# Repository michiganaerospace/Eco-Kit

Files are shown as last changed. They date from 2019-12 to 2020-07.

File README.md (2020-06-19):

# Eco-Kit
A Enviornmental Monitoring Kit

This is an Enviromental Monitoring Kit which M.A.C. has created in order to access live weather data easily.

To install the Eco Kit app you will want to download the github repository.

Windows: navigate to weather ui windows on an Anaconda Prompt. Type "pip install -r requirments.txt" . 
It should install the required librarys to the anaconda program and if all is successful its ready to run the windows application.

Mac: navigate to anaconda prompt and follow the directions in the "install text.txt" file. 

To run the application we use the spyder program included in the anaconda package.
You will want to go up to the top of spyder and open the file of the windows or macintosh version of the ECO Kit program.
It should be ready to run after that.

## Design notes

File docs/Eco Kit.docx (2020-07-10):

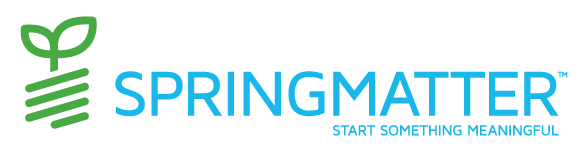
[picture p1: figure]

ECO KIT

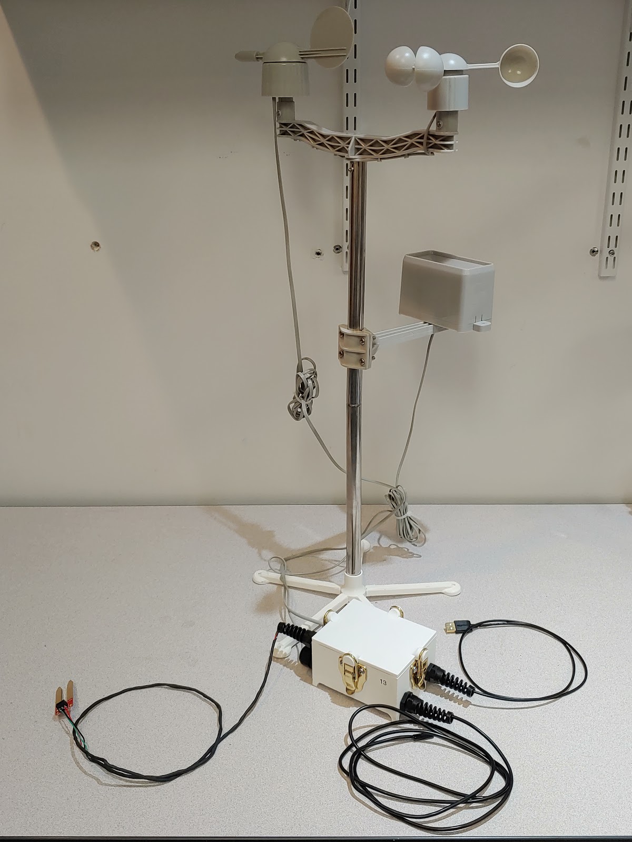
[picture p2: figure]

Table of content

WIFI setup – 3

Eco Kit setup – 3

Photon color codes - 3

Downloading the weather app- 4

Running App - 5

Using App – 6

Getting the Data from the Photon - 7

Setting Up Google Sheets - 8

Adding new weather station to weather app - 16

Connecting Wi-Fi to photon:

1. Power up photon
2. Navigate to https://setup.particle.io
3. Select Photon
4. Press continue with local file and download the setup file
5. Click the download and a new window should open up
6. Hold down SETUP on your Photon for 3 seconds until the LED begins blinking dark blue

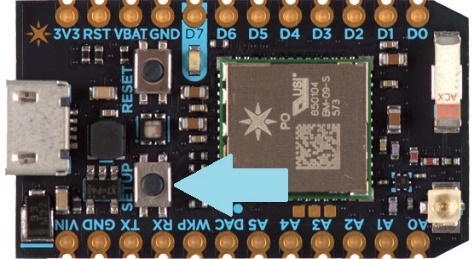
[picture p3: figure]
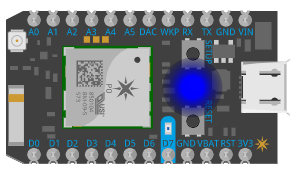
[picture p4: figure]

7. From your Wi-Fi network list, connect to the one named 'Photon-...'
8. If it displays “Error: HTTP timed out” reload the page
9. If your photon is breathing cyan you successfully connected

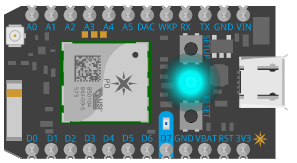
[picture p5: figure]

10. Select complete setup without naming your device
11. You can exit the page now

Eco Kit setup

1. Find a flat location to setup the Eco Kit
2. Place the soil moisture sensor and soil temperature sensor into dirt that you want to monitor
3. Plug the usb cable into a computer or USB wall charger to power the system up
4. The weather station should start reporting data
5. If data isn't reporting check the inside of the box and the photon board status will be displayed by the color it is emitting

Photon color codes

Breathing cyan - Board is connected to wifi

Blinking cyan - Actively connecting to wifi

Blinking green - Looking for wifi

Blinking dark blue - waiting for you to setup wifi

Breathing dark blue - wifi on but cannot connect to network

Breathing green - not connected to cloud

Downloading the weather app

1. Download a python ide for this app we will use anaconda.
2. Go to https://www.anaconda.com/distribution/#download-section and download the latest anaconda version for your operating system
3. Once anaconda is downloaded type in “Anaconda Navigator” to your search bar and left click “Anaconda Navigator”
4. Click launch on the Spyder app

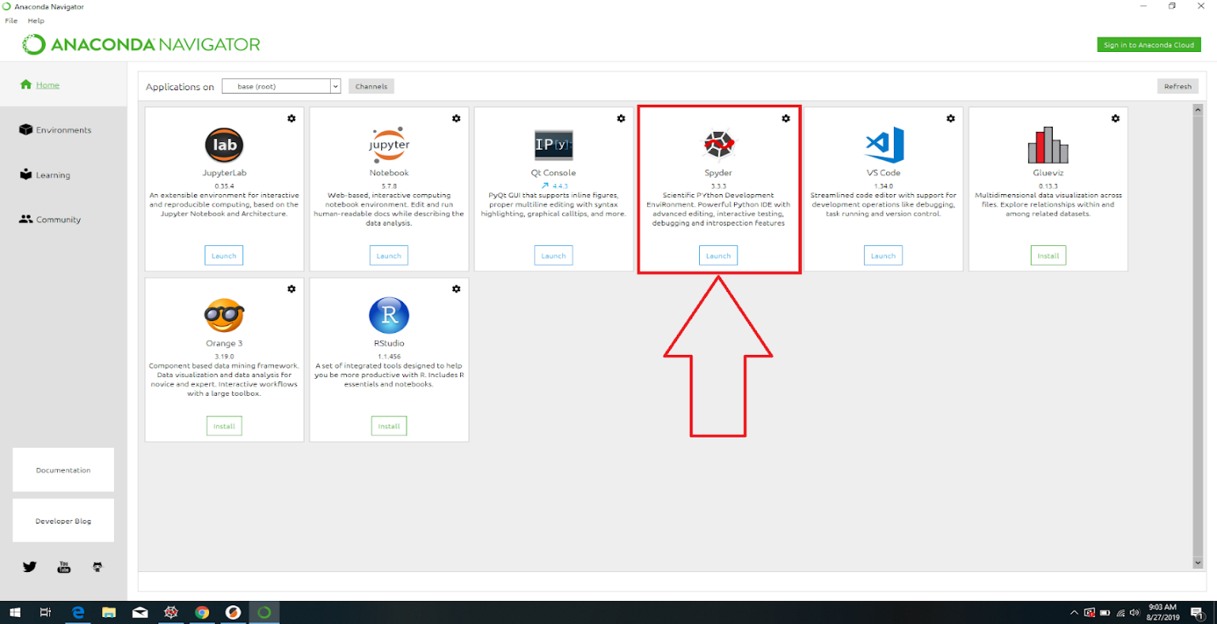
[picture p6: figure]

5. Type “pip install gspread” and “pip install oauth2client” into the console located in the right side of the screen

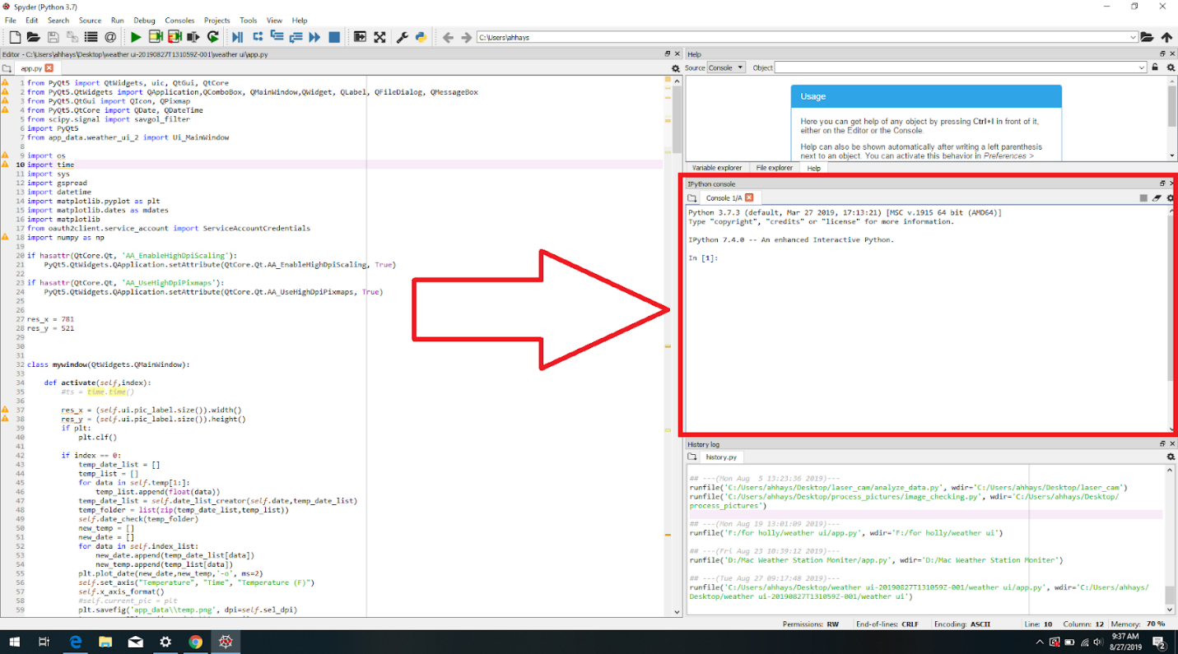
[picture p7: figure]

Running app

1. Launch Anaconda Navigator
2. Select launch on Spyder

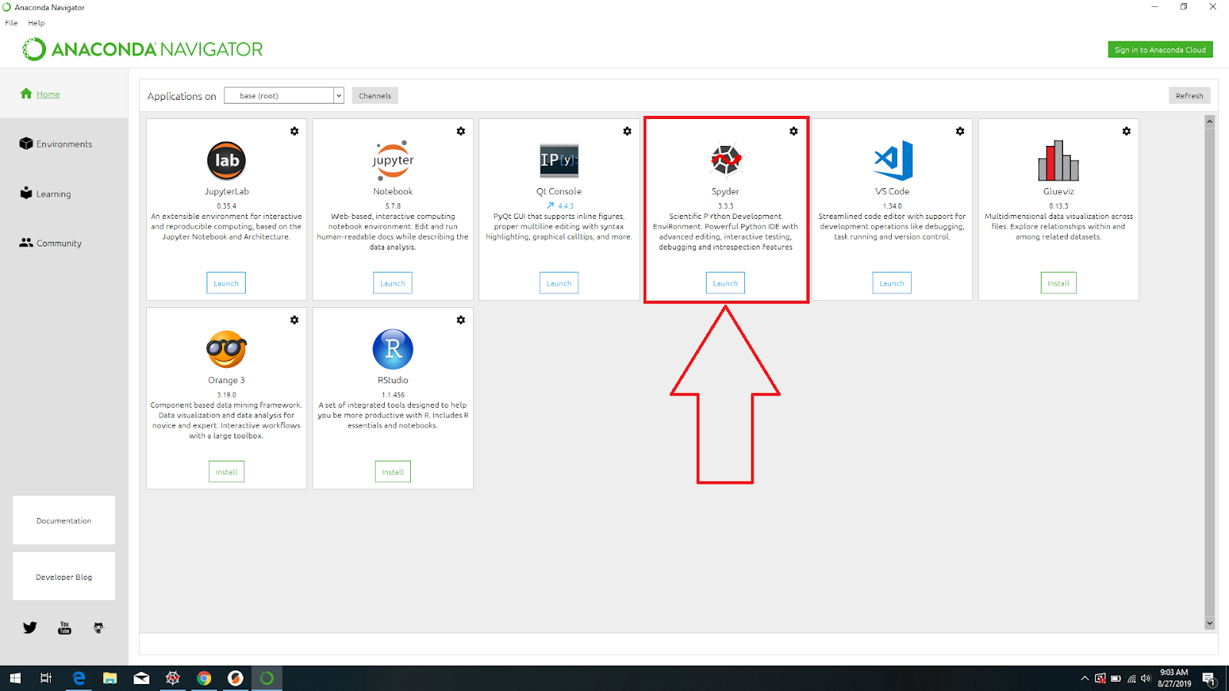
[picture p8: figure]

3. Select file from top right of spyder window and select “open”
4. Navigate to app.py in the weather ui folder and open it
5. Run app by selecting green arrow in the top of the spider window

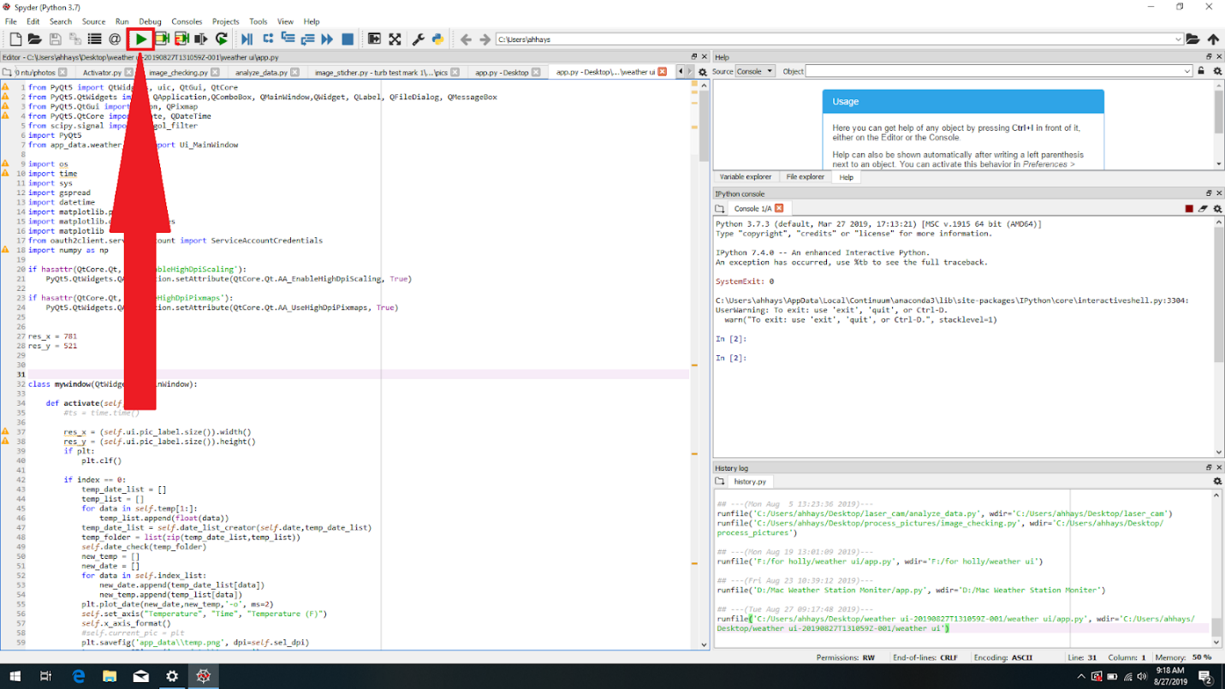
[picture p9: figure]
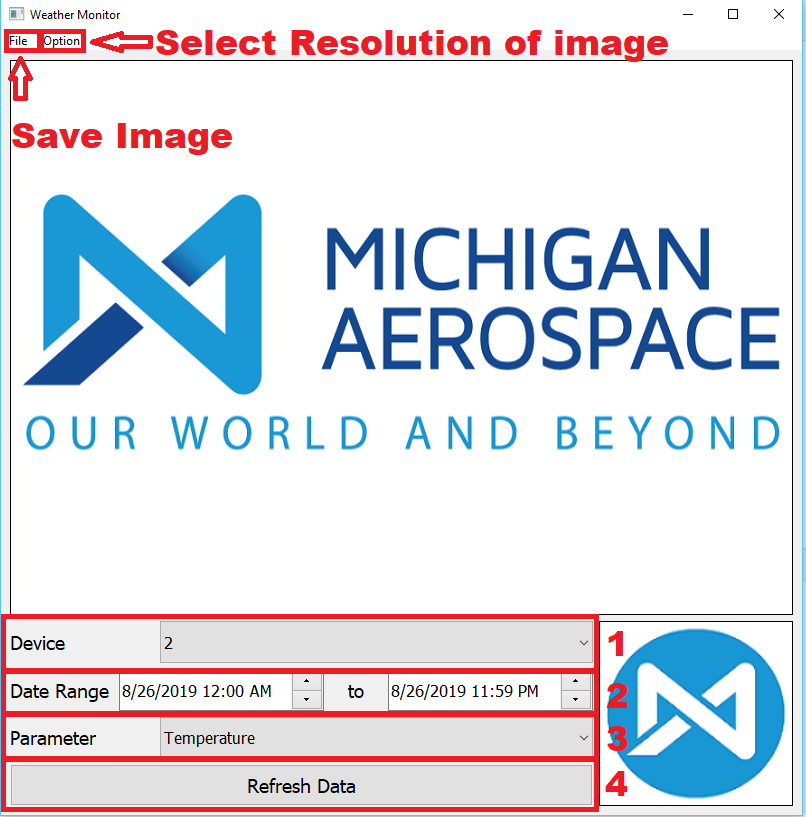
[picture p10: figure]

Once you have the Weather Monitor app running to get data you will need to:

1. Select a Device
2. Choose the data range of data that you want to see
3. Select which weather phenomenon you want to see
4. Then hit refresh data to obtain a graph of the data
5. This app downloads the data from google sheets and uses it to create these graphs. When you refresh data, it will take the newest points in the data range from google sheets if it doesn’t already have them.
6. To save the image, select file on the top left of the window and then save image and select the directory you want to save the image to.
7. To improve the resolution of this image, select options at the top left of the window and change the image resolution to a higher dpi

Getting the Data from the Photon

1. Go to particle.io
2. Login with openworlds@springmatter.org and the password Storm1777
3. Now, go to build.particle.io
4. First you will need to flash the Operation_Phoenix code to your device. To do so, you should click the two arrows on the side of the screen then click on Operation_Phoenix.

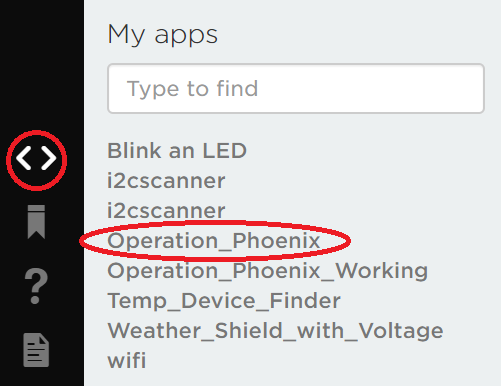
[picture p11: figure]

5. Once you have selected the correct device in the bottom right corner, click on the lightning bolt in the top left corner.
6. Once you have flashed the code to your device, the photon will begin to send data to Particle.io because of the Particle.publish line in the code.

Line 312 is the line you can change to modify the time between readings. If you change it you will need to reflash the code.

7. You can see data being published in the Particle.io Console

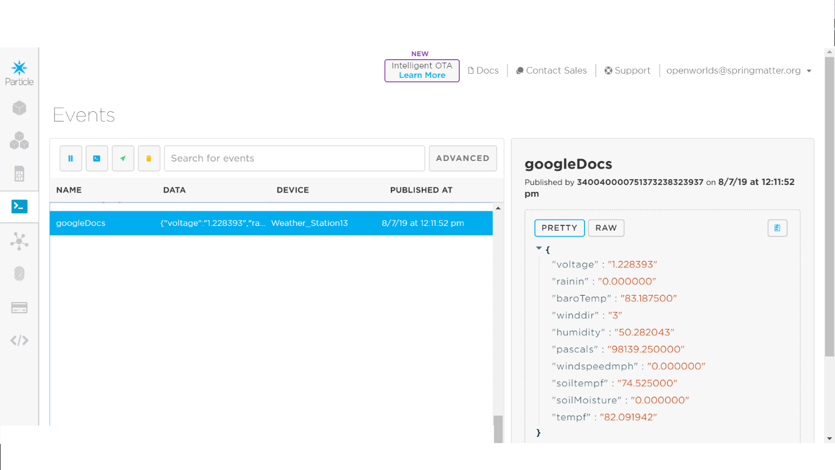
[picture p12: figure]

Setting Up Google Sheets

1. Once there is data streaming into Particle.io you can set up a Google sheet for a webhook to send this data to. You must use google chrome to get this to work
2. Login to the email: michiganaerospace1@gmail.com password: michaero
3. Create a new Google Sheet in Google Drive and Name it (Weather Station #)
4. Once you open your google sheet, you need to name the columns as shown below
5. Next you need to open the script editor in Google Sheets. To do this click on the Tools tab at the top, the click on Script editor

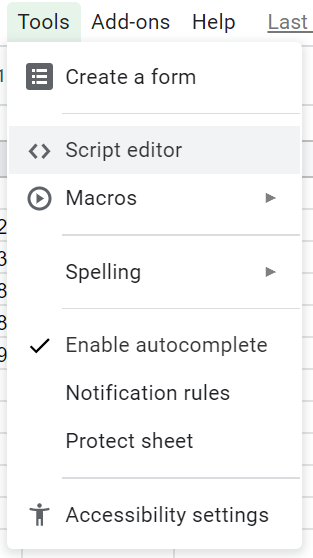
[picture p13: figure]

6. A Screen like this will pop up. Give the project a name (Weather Station # Project)

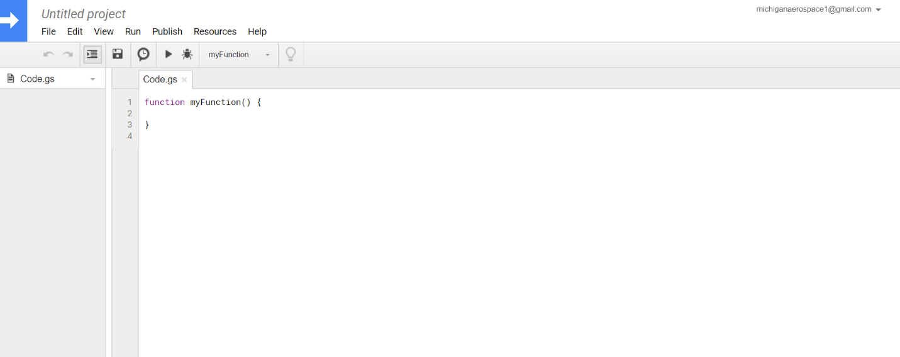
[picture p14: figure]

7. Delete what is currently under Code.gs and paste this code:

// original from: http://mashe.hawksey.info/2014/07/google-sheets-as-a-database-insert-with-apps-script-using-postget-methods-with-ajax-example/

function doGet(e){

return handleResponse(e);

}

// Usage

// 1. Enter sheet name where data is to be written below

var SHEET_NAME = "Sheet1";

// 2. Run > setup

//

// 3. Publish > Deploy as web app

// - enter Project Version name and click 'Save New Version'

// - set security level and enable service (most likely execute as 'me' and access 'anyone, even anonymously)

//

// 4. Copy the 'Current web app URL' and post this in your form/script action

//

// 5. Insert column names on your destination sheet matching the parameter names of the data you are passing in (exactly matching case)

var SCRIPT_PROP = PropertiesService.getScriptProperties(); // new property service

// If you don't want to expose either GET or POST methods you can comment out the appropriate function

function doPost(e){

return handleResponse(e);

}

function handleResponse(e) {

// shortly after my original solution Google announced the LockService[1]

// this prevents concurrent access overwritting data

// [1] http://googleappsdeveloper.blogspot.co.uk/2011/10/concurrency-and-google-apps-script.html

// we want a public lock, one that locks for all invocations

var lock = LockService.getPublicLock();

lock.waitLock(30000); // wait 30 seconds before conceding defeat.

try {

// next set where we write the data - you could write to multiple/alternate destinations

var doc = SpreadsheetApp.openById(SCRIPT_PROP.getProperty("key"));

var sheet = doc.getSheetByName(SHEET_NAME);

// we'll assume header is in row 1 but you can override with header_row in GET/POST data

var headRow = e.parameter.header_row || 1;

var headers = sheet.getRange(1, 1, 1, sheet.getLastColumn()).getValues()[0];

var nextRow = sheet.getLastRow()+1; // get next row

var row = [];

// loop through the header columns

for (i in headers){

if (headers[i] == "Timestamp"){ // special case if you include a 'Timestamp' column

row.push(new Date());

} else { // else use header name to get data

row.push(e.parameter[headers[i]]);

}

}

// more efficient to set values as [][] array than individually

sheet.getRange(nextRow, 1, 1, row.length).setValues([row]);

// return json success results

return ContentService

.createTextOutput(JSON.stringify({"result":"success", "row": nextRow}))

.setMimeType(ContentService.MimeType.JSON);

} catch(e){

// if error return this

return ContentService

.createTextOutput(JSON.stringify({"result":"error", "error": e}))

.setMimeType(ContentService.MimeType.JSON);

} finally { //release lock

lock.releaseLock();

}

}

function setup() {

var doc = SpreadsheetApp.getActiveSpreadsheet();

SCRIPT_PROP.setProperty("key", doc.getId());

}

8. Save this code then Run setup.

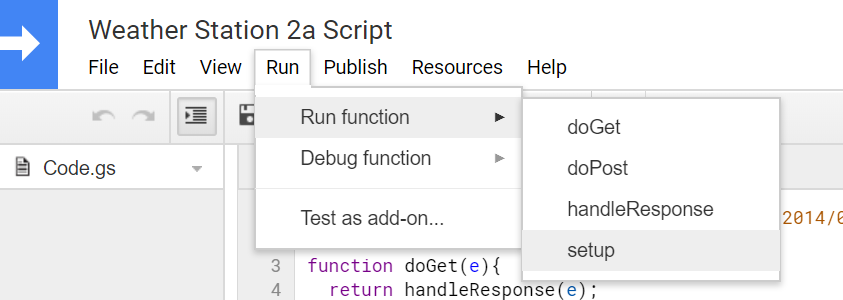
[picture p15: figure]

9. A screen will come up about permissions with the document. You will need to hit advanced settings then allow.
10. Next, click on the Publish tab and the Deploy as a Web App

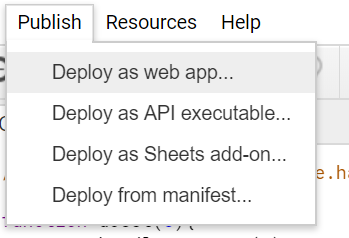
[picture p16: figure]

11. That will bring up this screen:

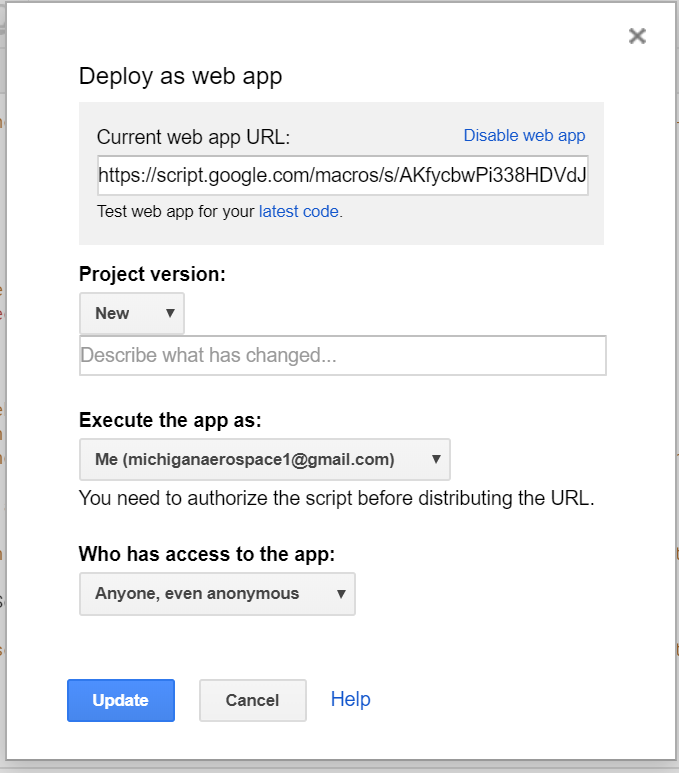
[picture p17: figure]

12. Set the Project version to new, the execute app as to Me and the access to anyone even anonymous. Click Deploy.
13. That will bring up this screen:

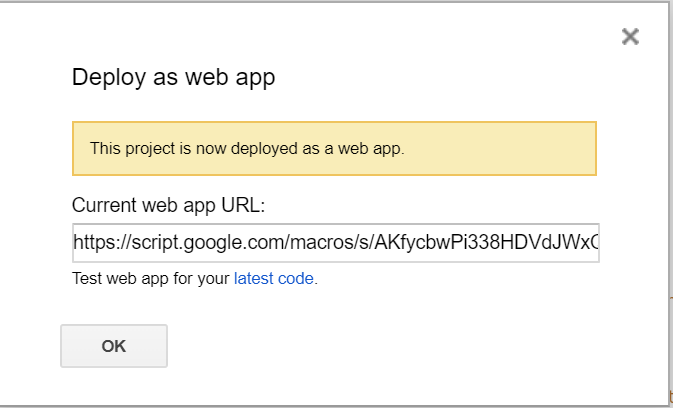
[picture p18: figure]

14. Copy the Current web app URL to be used in a Particle Webhook and click OK

Setting Up a Particle Webhook

1. Open the Particle.io console and click on integrations
2. Click on new integration

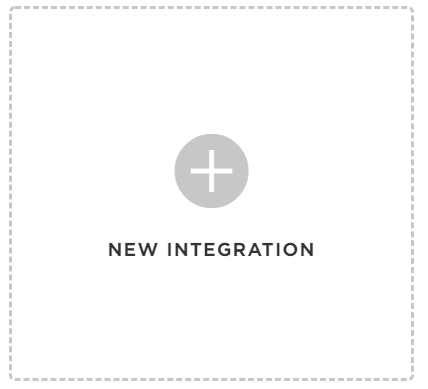
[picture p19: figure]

3. Click on Webhook
4. Enter the event name googleDocs. Paste the URL you copied from the google script. Select your device.

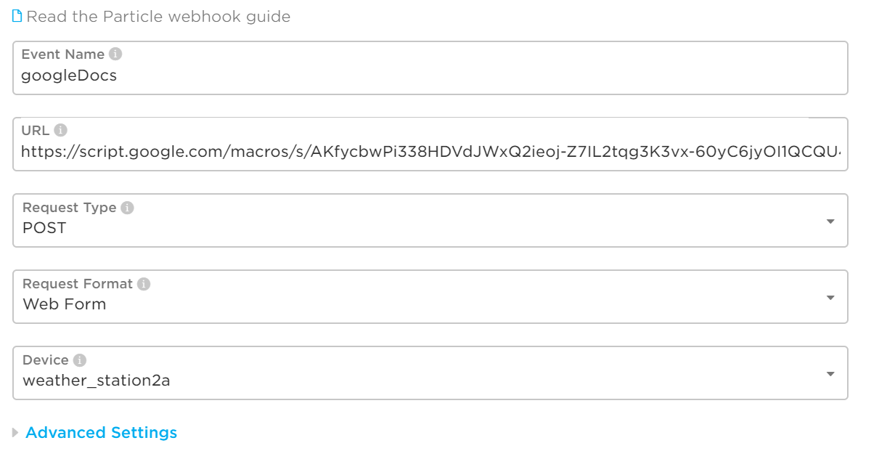
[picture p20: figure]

5. Click on Advanced Settings then custom for form fields. Enter each field as seen below

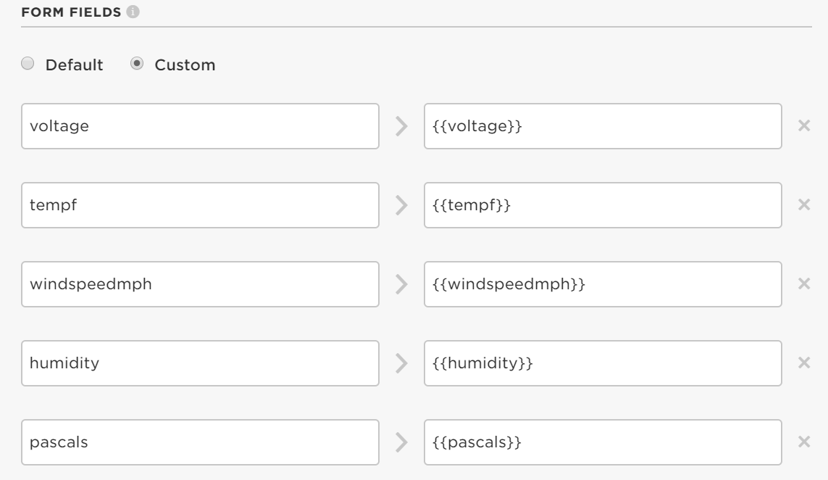
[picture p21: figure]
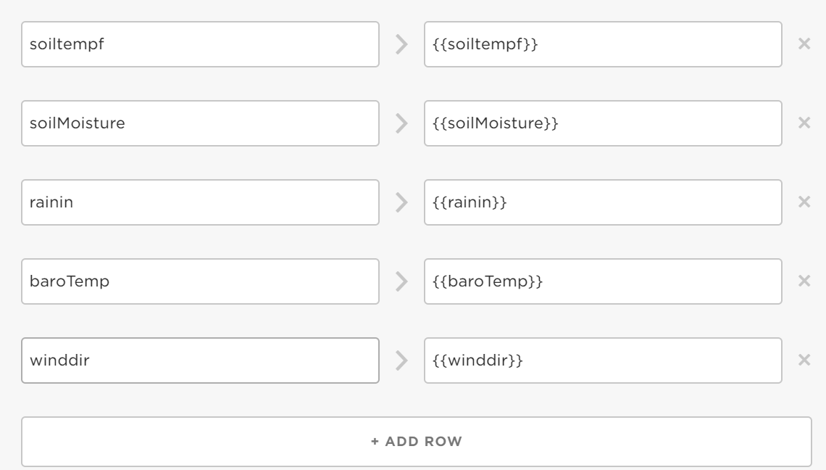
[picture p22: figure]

6. Under Http Headers enter as seen below

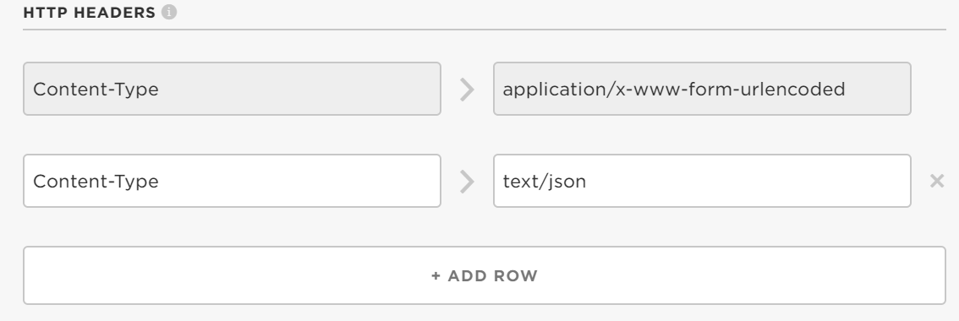
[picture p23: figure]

7. At the bottom of the page click create webhook. If you are editing your webhook, you will need to hit save.
8. You should now be able to go to the events tab on the Particle.io console and see hooks being sent to Google Sheets

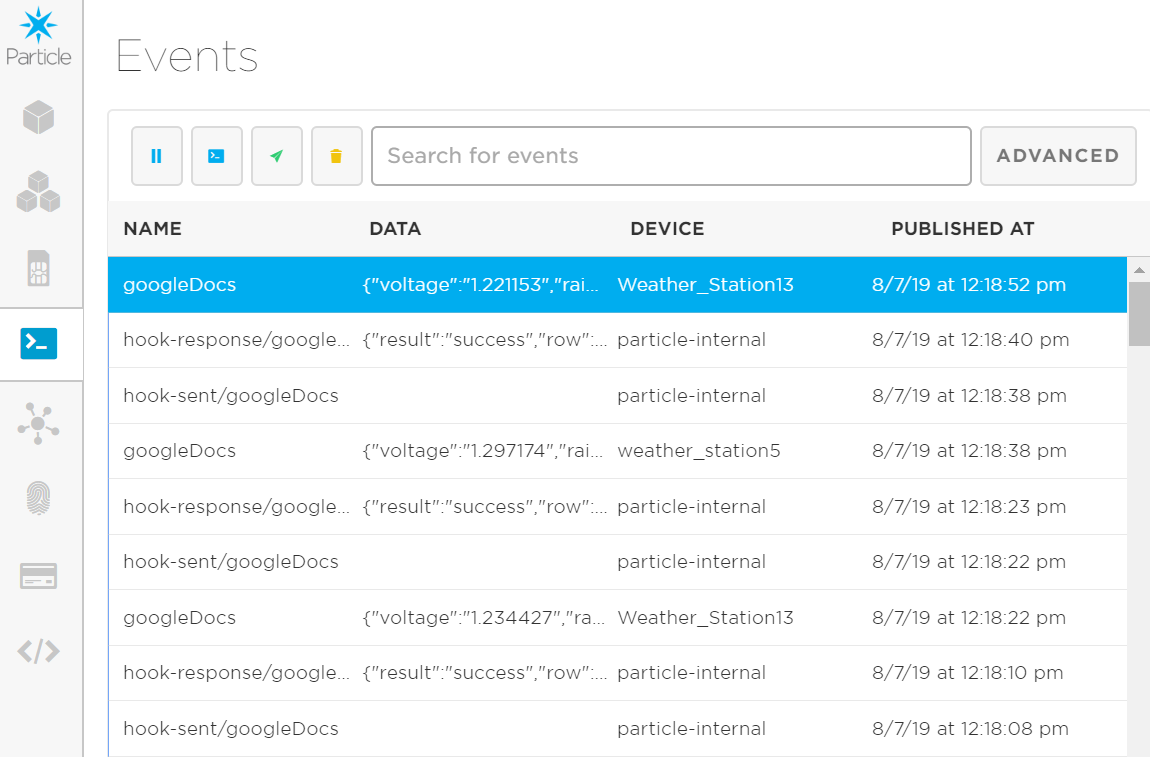
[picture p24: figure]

9. Data should now be streaming in your Google Sheet

Adding new weather station to weather app

1. Navigate to the client secret file located in the app_data or main folder
2. Right click and select edit
3. Select and copy the client_email which is “weather@weather-247217.iam.gserviceaccount.com”
4. Return to the google sheet and share this with our client_email so it can access the sheet.
5. Run the weather app if not familiar check the section on running the app
6. In the top left section of weather app select option and then Add Device
7. A pop-up window should ask you the number of your weather station
8. Enter the weather station number from your google sheets example (Weather Station 5) just enter “5”

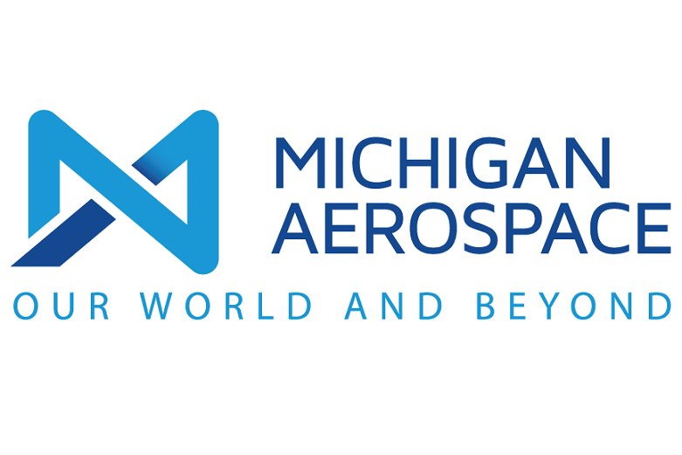
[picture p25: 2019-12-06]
weather ui windows/app_data/MAC-Decal-MASTER.png

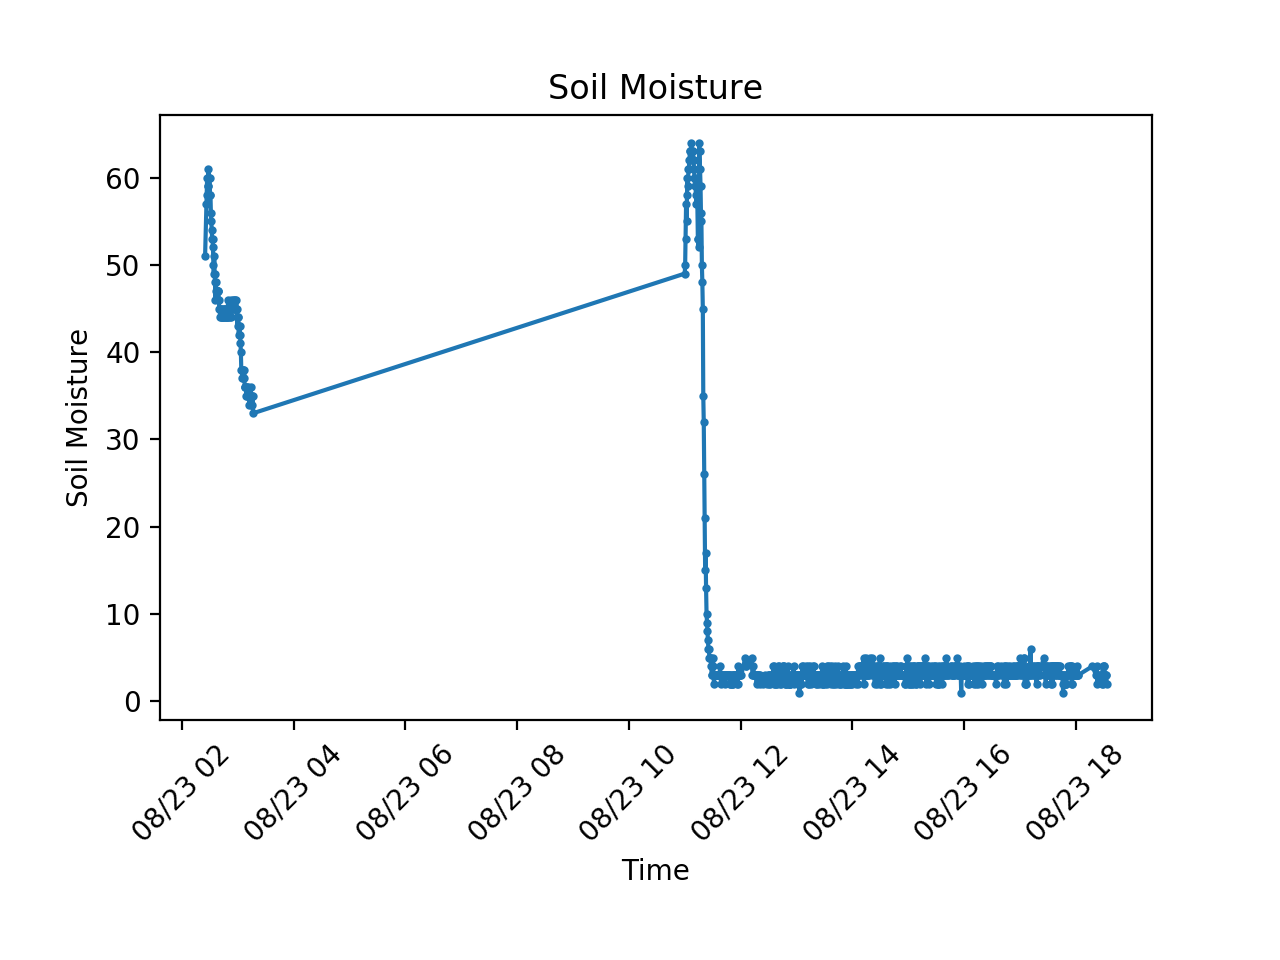
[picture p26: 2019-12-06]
weather ui mac/sm.png

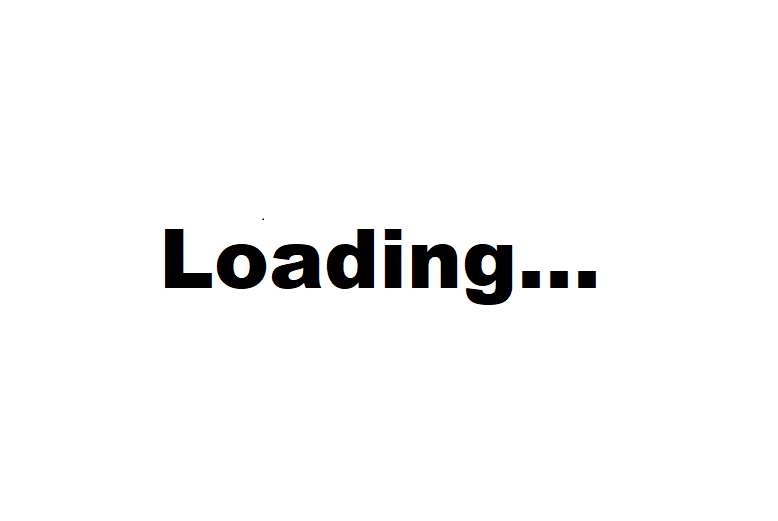
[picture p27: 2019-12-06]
weather ui mac/loading.png

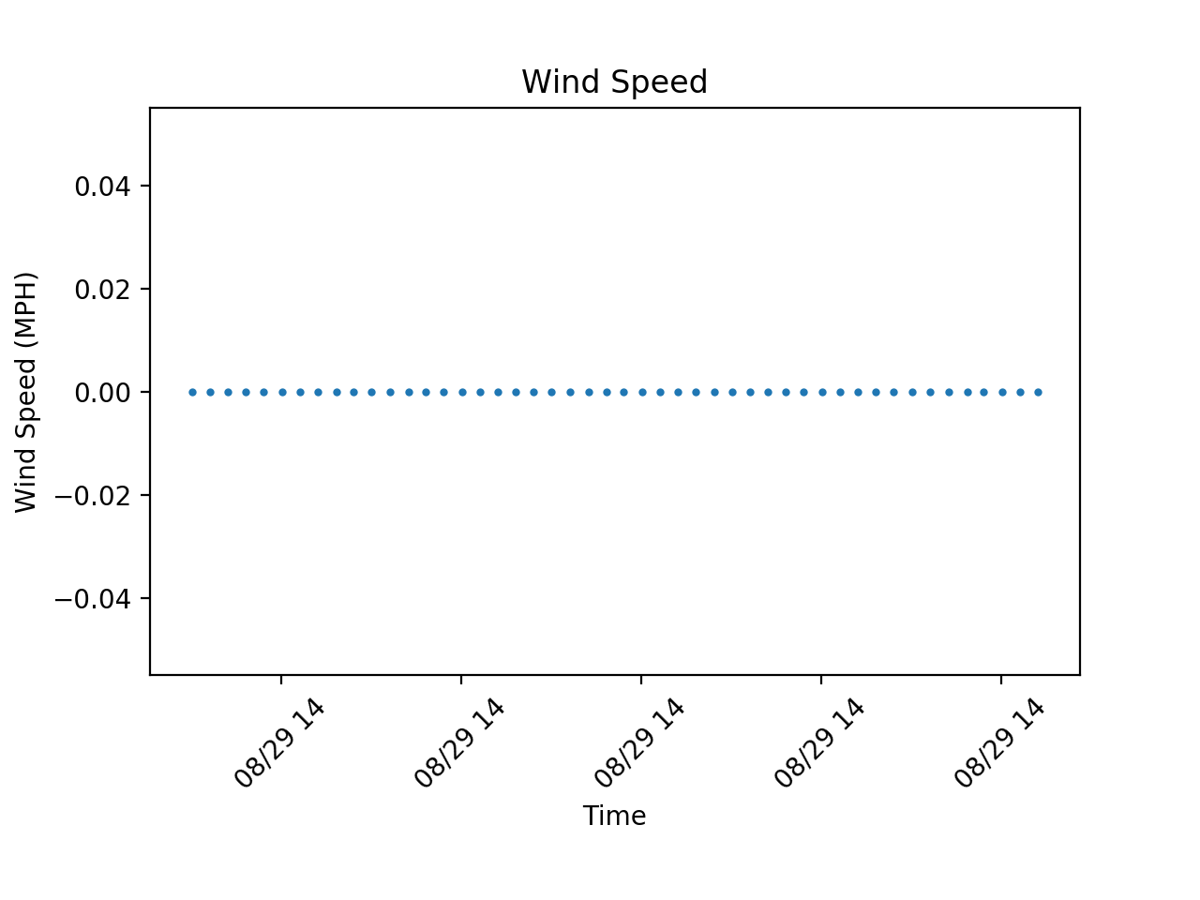
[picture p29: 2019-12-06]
weather ui windows/app_data/wind.png

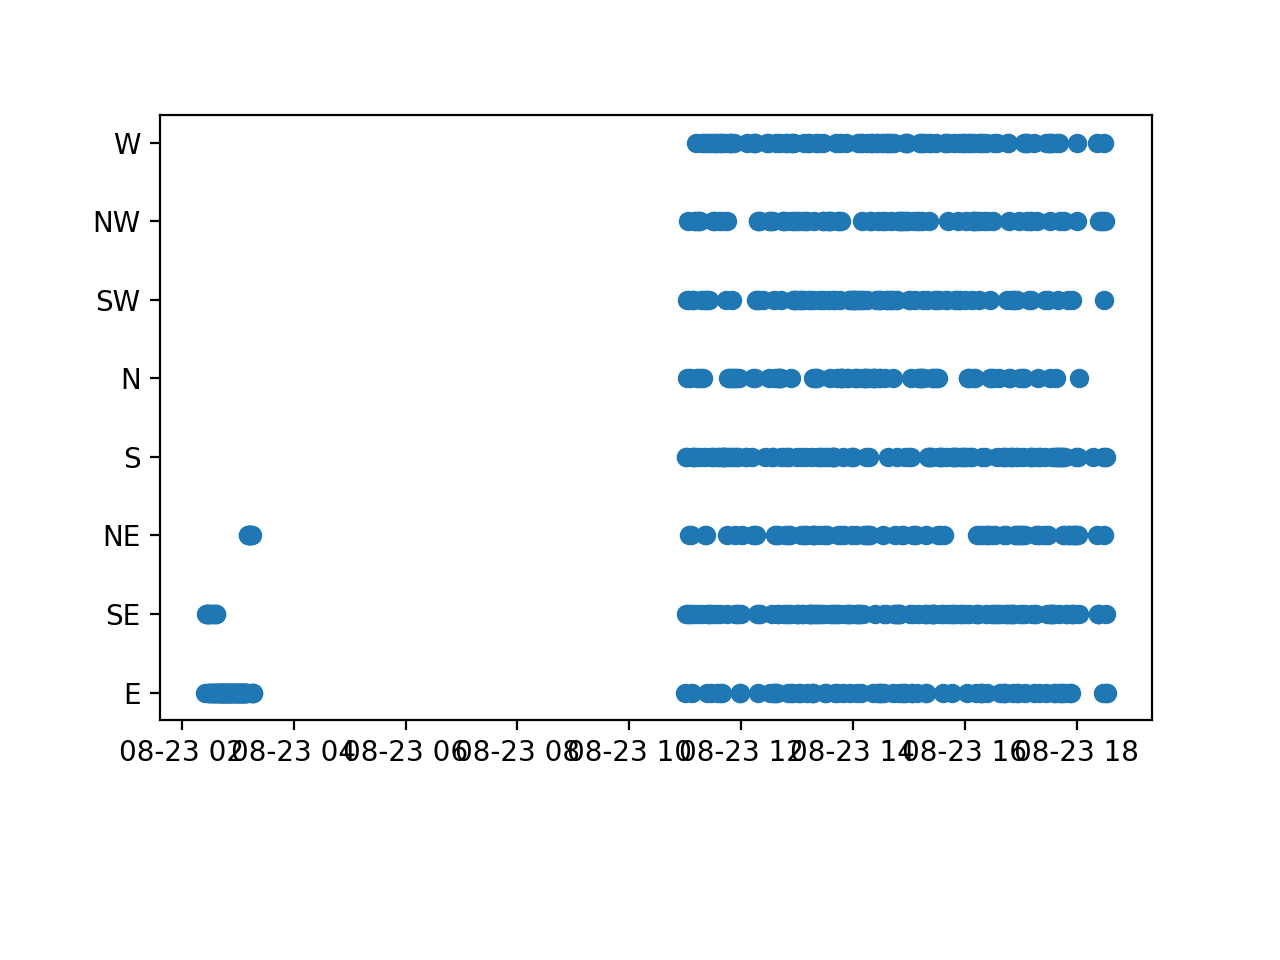
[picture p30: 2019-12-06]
weather ui mac/dir.png

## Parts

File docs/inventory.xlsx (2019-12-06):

Inventory | Link | Price | Qty
Photon Weather Shield | https://www.sparkfun.com/products/13674 | $34.95 | 10
Weather Station | https://www.sparkfun.com/products/8942?_ga=2.250102662.1883355530.1560449534-755629654.1560449534 | $76.95 | 10
Photon Board | https://store.particle.io/collections/wifi | $19.00 | 10
Electron Board | https://store.particle.io/collections/wifi | $69.00 | ?
Round Strap Clamp
Brass clamps | https://www.mcmaster.com/draw-latches | $10.41 | 8
Soil moisture sensor | https://www.sparkfun.com/products/13322 | $5.95 | 10
Soil temperature probe | https://www.sparkfun.com/products/11050 | $11.95 | 10
Vermont American 3/8 - 18 NPT Pipe Tap | https://www.amazon.com/Vermont-American-20353-Carbon-Steel/dp/B0009VQJI2?hvadid={creative}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 | $7.11 | 1
RS Components Cable gland M20*1.5 |  | $6.84 | 6
Heatshrink 1/8" * 4' |  | $1.10 | 10
#8-32x3/16" phillips machine screw | https://www.amazon.com/Stainless-Phillips-Machine-Bolt-Dropper/dp/B07B7J4X6J?s=industrial | $9.98 | 2
4-40x3/16" allen screws
AmazonBasics USB 2.0 A-Male to Micro B Charger Cable, 3 feet, Black | https://www.amazon.com/AmazonBasics-Male-Micro-Cable-Black/dp/B0711PVX6Z?hvadid=198093101467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 | $4.99 | 10
3d printing filiment
4-40 tap
bigger tap
O ring mcmaster 9557K246 dash 247 Water- and Steam-Resistant EPDM O-Rings | https://www.mcmaster.com/o-rings | $9.64 | 1

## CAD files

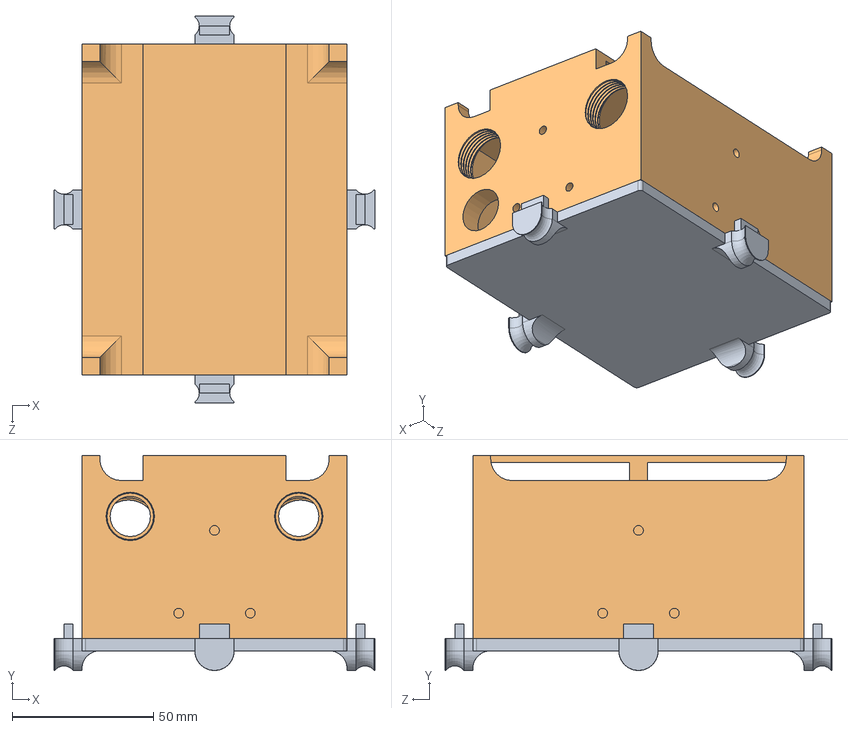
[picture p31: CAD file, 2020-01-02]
3d models/Assem_BOX.SLDASM
113.7 x 76.2 x 137.1 mm
lid
finished_box

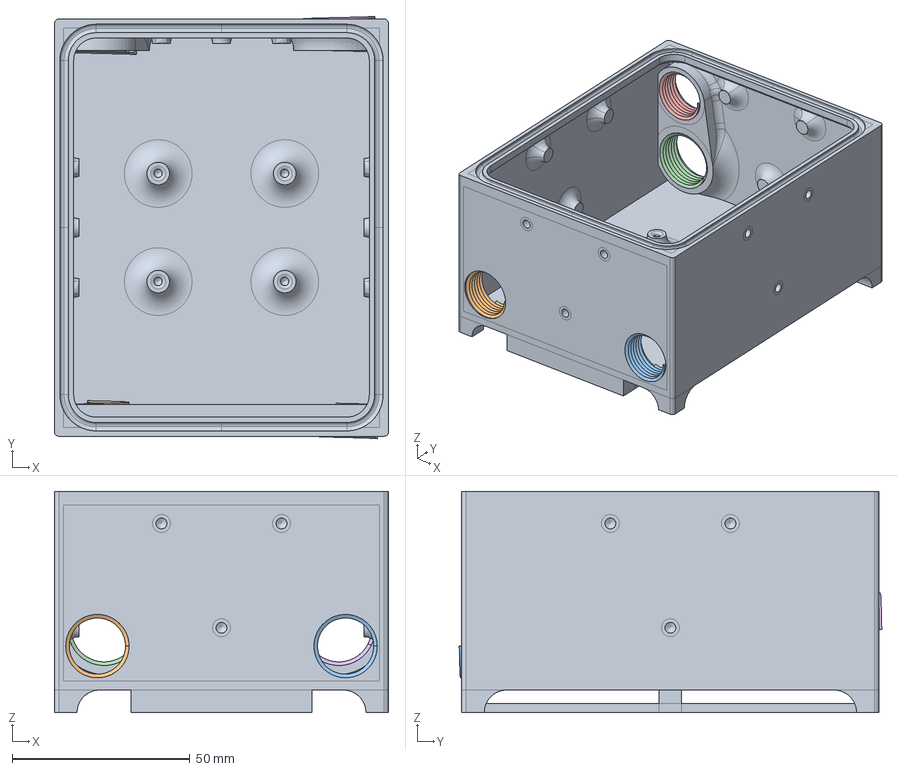
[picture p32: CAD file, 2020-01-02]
3d models/completed bottom container weather station.FCStd
94.0 x 118.9 x 62.2 mm

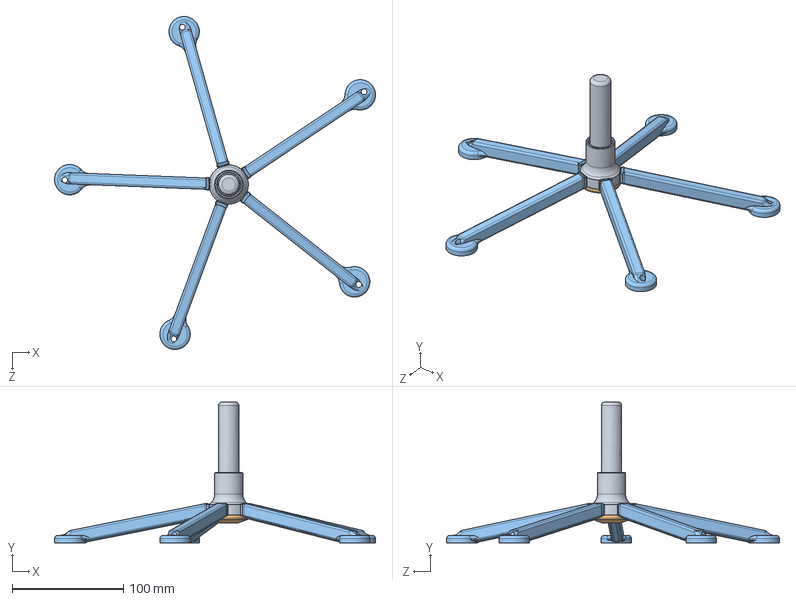
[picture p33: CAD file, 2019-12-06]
3d models/Assem1.SLDASM
289.2 x 127.0 x 300.0 mm
base
base support
oldleg x 5

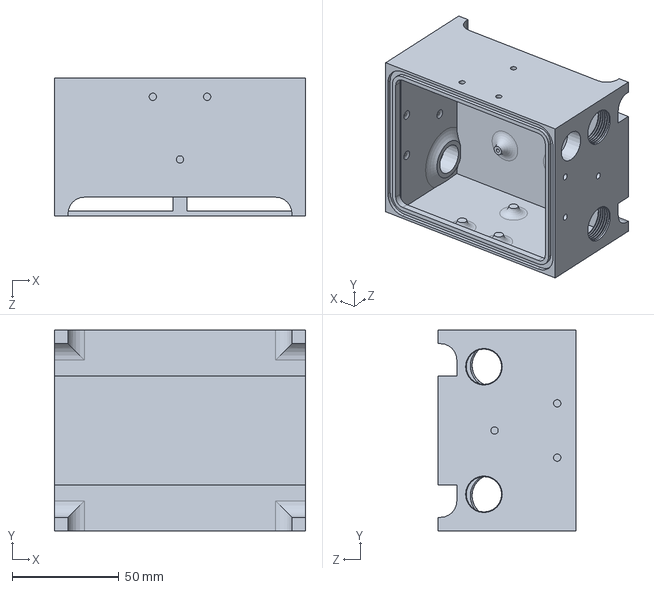
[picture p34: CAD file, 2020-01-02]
3d models/finished_box.SLDPRT
117.5 x 94.0 x 64.8 mm

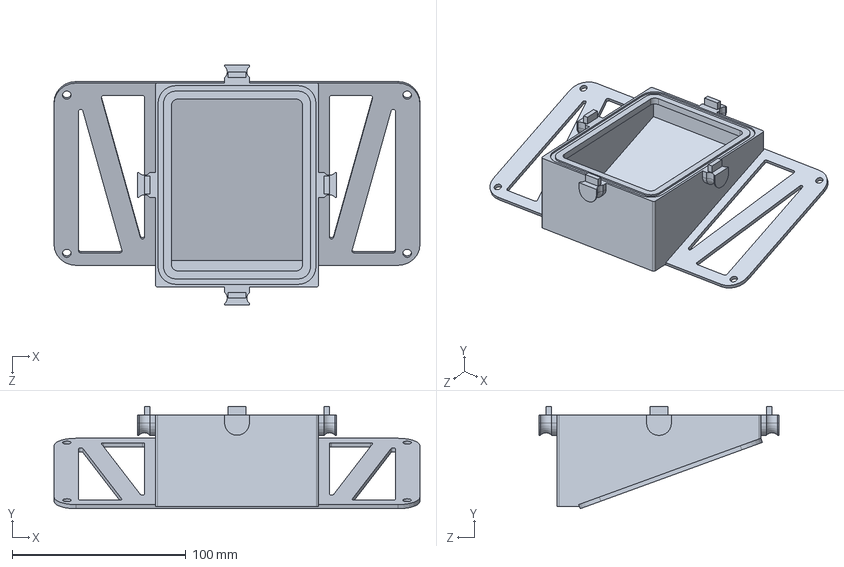
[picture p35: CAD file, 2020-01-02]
3d models/lid2.SLDPRT
210.8 x 59.0 x 138.2 mm

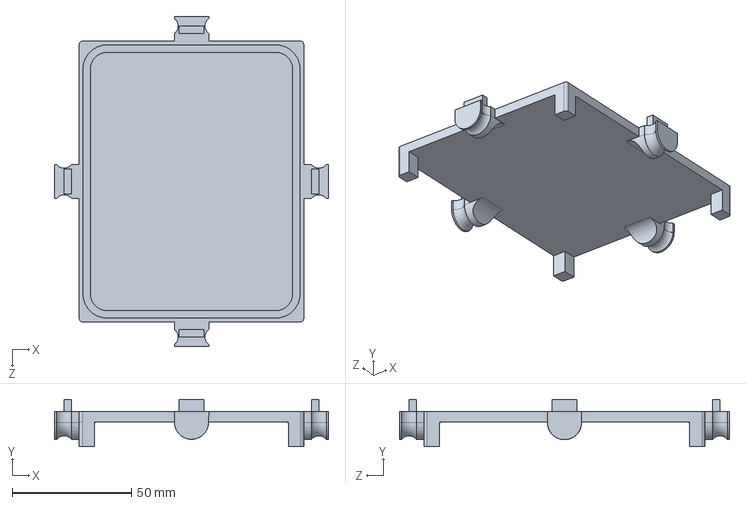
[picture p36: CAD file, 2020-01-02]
3d models/lid.SLDPRT
114.7 x 19.7 x 138.2 mm

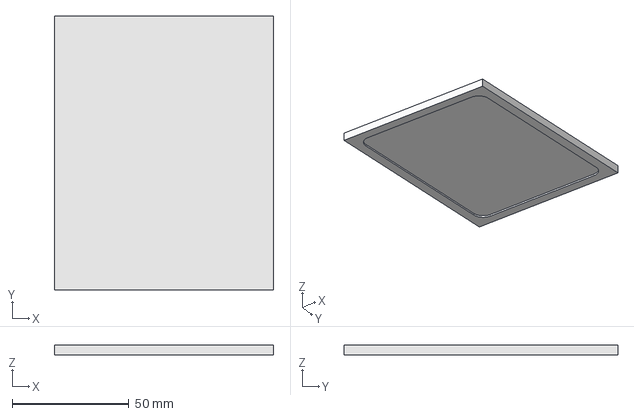
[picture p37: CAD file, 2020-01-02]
3d models/wethershield_lid.FCStd
94.0 x 117.5 x 4.45 mm

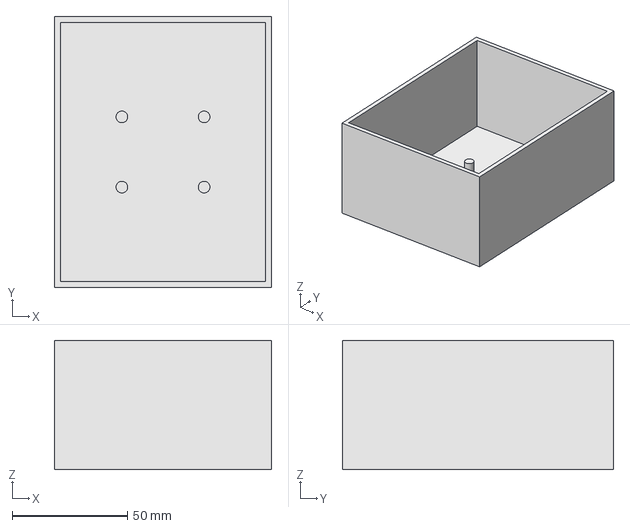
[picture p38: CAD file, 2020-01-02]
3d models/box.FCStd
94.0 x 117.5 x 55.9 mm

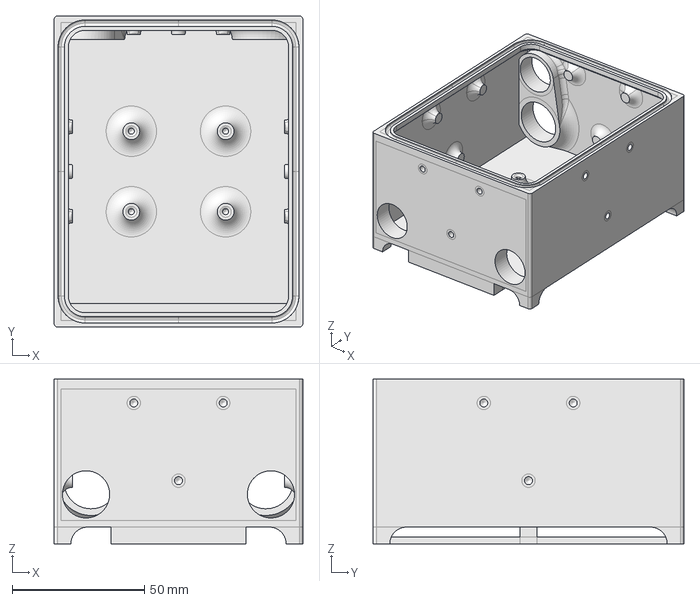
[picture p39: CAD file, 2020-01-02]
3d models/box_work_in_progress.FCStd
94.0 x 117.5 x 62.2 mm

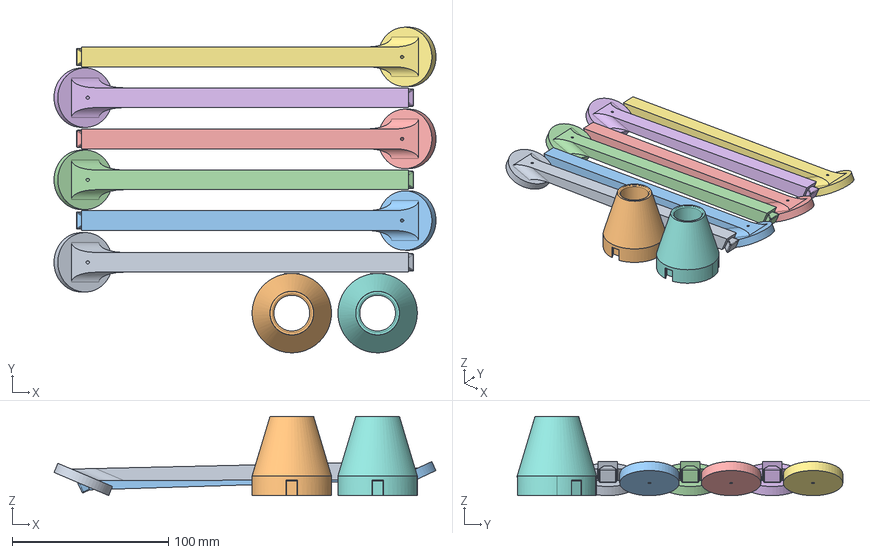
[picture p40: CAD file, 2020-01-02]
3d models/new tripod legs.FCStd
244.8 x 208.7 x 50.8 mm

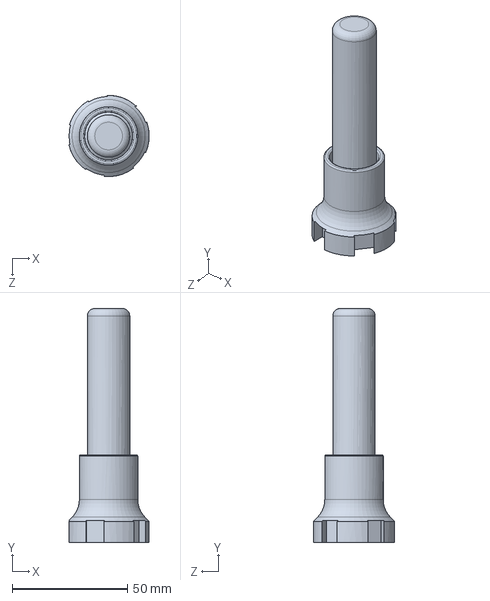
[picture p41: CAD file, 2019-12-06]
3d models/base.SLDPRT
34.9 x 101.6 x 35.3 mm

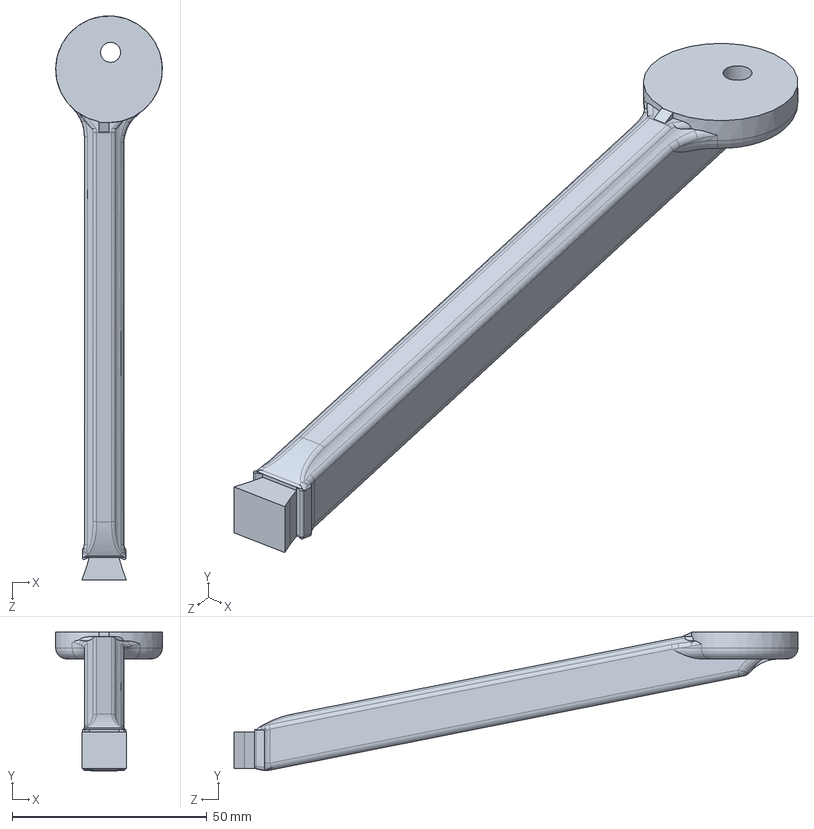
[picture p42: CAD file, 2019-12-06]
3d models/oldleg.SLDPRT
27.4 x 35.6 x 144.9 mm

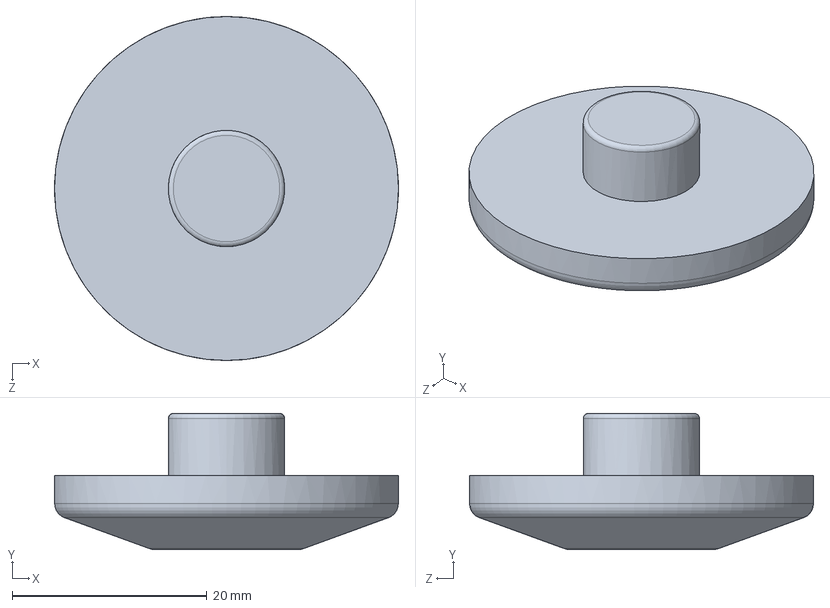
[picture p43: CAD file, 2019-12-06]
3d models/base support.SLDPRT
35.3 x 14.0 x 35.3 mm

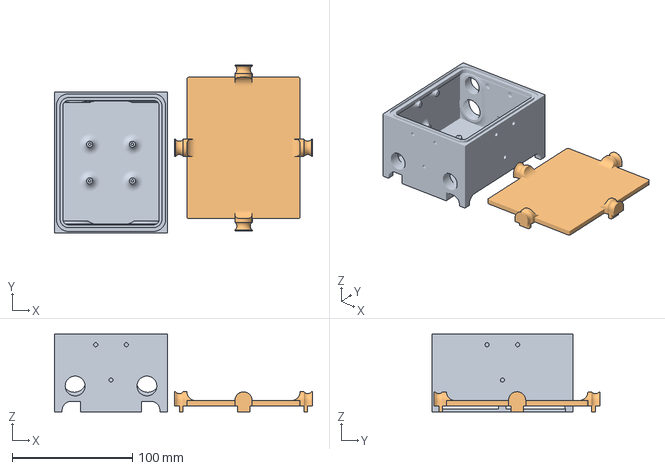
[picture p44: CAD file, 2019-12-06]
3d models/finished_box_v10.3mf
214.5 x 140.0 x 64.8 mm
finished_box_v10.STL
lid_v5.STL

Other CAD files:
3d models/finished_box_v2.SLDPRT
3d models/finished_box_v100.STL
3d models/lidsolar.SLDPRT
3d models/baseman.SLDPRT
3d models/finished_box_v10.STL
3d models/finished_box_v5.STL

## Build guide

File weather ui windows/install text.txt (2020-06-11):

Launch app.py with spider

Into the console on the right side of the screen type 

pip install gspread
pip install oauth2client
pip install scipy

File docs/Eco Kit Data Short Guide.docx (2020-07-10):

Collecting Data thru google drive

Power up eco kit

Login to google drive https://drive.google.com/drive/my-drive

UN: michiganaerospace1@gmail.com

PW: michaero

Select sheet with your eco kit number and it should be updating with values from your eco kit

Electron setup

A great video explaining the Particle Electron setup in detail that cannot be explained in a manual easily

https://www.youtube.com/watch?v=T60GEfMFwIY

Collecting Data locally (create excel sheets and graphs)

Navigate to https://github.com/michiganaerospace/Eco-Kit

Download the file “serial plotter” from the github

You will also need the spider python compiler available at https://www.spyder-ide.org/

Once you have both files run the serial plotter program thru the spider compiler. You will need to change one value in the serial plotter program which is the com port.

Type device manager into your computer search bar and open it. Under com port in the device manager the electron should appear.

You’ll type in your com port number to line 79 of the python code.

Run the serial plotter program.

it will display data on graphs as your weather station gets data.

If the screen is blank at the beginning it is waiting for a signal from the eco kit.

When the program is exited it will complete an excel file with the data you collected onto the graphs.

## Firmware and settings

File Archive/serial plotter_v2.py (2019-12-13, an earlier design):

import serial
import matplotlib.pyplot as plt
from matplotlib import animation
import csv
import xlwt
from tempfile import TemporaryFile
from datetime import datetime

t = 0
i=0
x=list()
y=list()
y_2=list()
y_3=list()
y_4=list()
y_5=list()
y_6=list()
y_7=list()
y_8=list()
time_list= list()
i=0
p = 0
def handle_close(evt):
    global x
    global y
    global y
    global y_2
    global y_3
    global y_4
    global y_5
    global y_6
    global y_7
    global time_list
    book = xlwt.Workbook()
    
    sheet1 = book.add_sheet('sheet1')
    sheet1.write(1,2,'Wind Speed')
    sheet1.write(1,3,'Rain')
    sheet1.write(1,4,'Temperature')
    sheet1.write(1,5,'Humidity')
    sheet1.write(1,6,'Temperature 2')
    sheet1.write(1,7,'Pressure')
    sheet1.write(1,8,'Soil Moisture')
    sheet1.write(1,9,'Date_Time')
    
    for i,e in enumerate(x):
        sheet1.write(i+2,1,e)
        
    for i,e in enumerate(y):
        sheet1.write(i+2,2,e)

    for i,e in enumerate(y_2):
        sheet1.write(i+2,3,e)
        
    for i,e in enumerate(y_3):
        sheet1.write(i+2,4,e)
    
    for i,e in enumerate(y_4):
        sheet1.write(i+2,5,e)
        
    for i,e in enumerate(y_5):
        sheet1.write(i+2,6,e)
        
    for i,e in enumerate(y_6):
        sheet1.write(i+2,7,e)
        
    for i,e in enumerate(y_8):
        sheet1.write(i+2,8,e)
        
    for i,e in enumerate(time_list):
        sheet1.write(i+2,9,e)
    
    name = "Weather_data.xls"
    book.save(name)
    book.save(TemporaryFile())
    ser.close()
# Find photon serial port and type in below
#VVVVVVVVVVVVVVVVVVVVVVVVVVVVVVVV
ser = serial.Serial('COM25',9600)
ser.close()
ser.open()
fig = plt.figure(figsize=(10,6))
fig.canvas.mpl_connect('close_event',handle_close)
ax1 = fig.add_subplot(3,2,1)
ax1.set_ylabel('Wind Speed')
ax2 = fig.add_subplot(3,2,2)
ax2.set_ylabel('Rain')
ax3 = fig.add_subplot(3,2,3)
ax3.set_ylabel('Temperature')
ax4 = fig.add_subplot(3,2,4)
ax4.set_ylabel('Humidity')
ax5 = fig.add_subplot(3,2,5)
ax5.set_ylabel('Soil Moisture')
ax6 = fig.add_subplot(3,2,6)
ax6.set_ylabel('Pressure')
plt.subplots_adjust(wspace = 0.6, hspace = 0.3)

def animate(i):
    global p
    if (p != 0):
        i = i + 1
    data = ser.readline()
    data_store = str(data).split(":")
    soil_moisture = data_store[15].split("\\")
    time_list.append(str(datetime.now()))
    x.append(i)
    y.append(float(data_store[1]))
    y_2.append(float(data_store[3]))
    y_3.append(float(data_store[5]))
    y_4.append(float(data_store[7]))
    y_5.append(float(data_store[9]))
    y_6.append(float(data_store[11]))
    y_8.append(float(soil_moisture[0]))
    ax1.clear
    ax1.plot(x,y)
    ax2.plot(x,y_2)
    ax3.plot(x,y_3)
    ax4.plot(x,y_4)
    ax5.plot(x,y_8)
    ax6.plot(x,y_6)
    p = p + 1
    
ani = animation.FuncAnimation(fig, animate, interval=20000)
plt.show()
